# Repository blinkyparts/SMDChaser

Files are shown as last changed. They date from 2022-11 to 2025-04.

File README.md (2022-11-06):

# SMD_Lauflicht

The running light is achieved by a circuit of a clockgenerator NE555 (U1) and two shift registers TI4017 (U2, U3). The NE555 uses the clock signal to shift one bit through both shift registers. At the end the circuit is reset and the cycle starts anew. The outputs of U2 controls the 20 LEDs (D1-D20). Since the TI4017 only has 10 outputs, one output controls  two LEDs. U3 controls one transistor each (Q1, Q2) using two outputs, which alternately pull D1-D10 or D11-D20 to GND. This process repeats itself.



- Status: **Complete**
- Difficulty: **4/5**

### Parts List

| Pos.|References 	| Value 		| Quantity | 
| --- | --- | --- | --- |
|1 | C1, C2 	| 100n F 		| 2 | 
|2 |	C 	| 1µ F 		| 1 |
|3 | R1-R20 	| 82 Ohm 		| 20 |
|4 | R21, R22 	| 100k Ohm 		| 2 |
|5 | R23, R24 	| 1k Ohm 		| 2 |
|6 | D1-D20 	| LED 		| 20 |
|7 | U1 	| NE555 		| 1 |
|8 | U2, U3 	| TI4017 		| 2 |
|9 | SW1 	| SW_DPDT_x2  		| 1 |
|10 | Q1, Q2 	| BC850 		| 2 |
|12 | Battery Holder	| Battery_Holder	| 1 |
|13 | Battery 	| CR2032 		| 1 |
|14 | PCB 	| SMD-Lauflicht		| 1 |

### Manual
You can find the manual and pictures of every step in the manual folder.

## PCB Layout
The PCB-Layout can be found on Github: tbd

## Video
A video of the running PCB can be found here: [YouTube](https://youtu.be/Xx-zP-Ia8_w)

## Copyright and Authorship
- PCB-Layout: [CC-BY-SA 4.0](https://creativecommons.org/licenses/by-sa/4.0/) - [Taxxizz](https://twitter.com/Taxxizz)
- Manual (TeX): [LPPL](https://www.latex-project.org/lppl.txt) - [Marei Peischl](https://peitex.de)
- Manual (pdf): [CC-BY-SA 4.0](https://creativecommons.org/licenses/by-sa/4.0/) - [Binary Kitchen e.V.](https://www.binary-kitchen.de)

### Buy Soldering Kits
If you want to buy the parts and PCB for a soldering kit you can find everything here: [shop.blinkyparts.com - Running Light](https://shop.blinkyparts.com/en/SMD-running-light-Soldering-kit-for-the-proper-learning-of-soldering-SMD-components/blink233142)

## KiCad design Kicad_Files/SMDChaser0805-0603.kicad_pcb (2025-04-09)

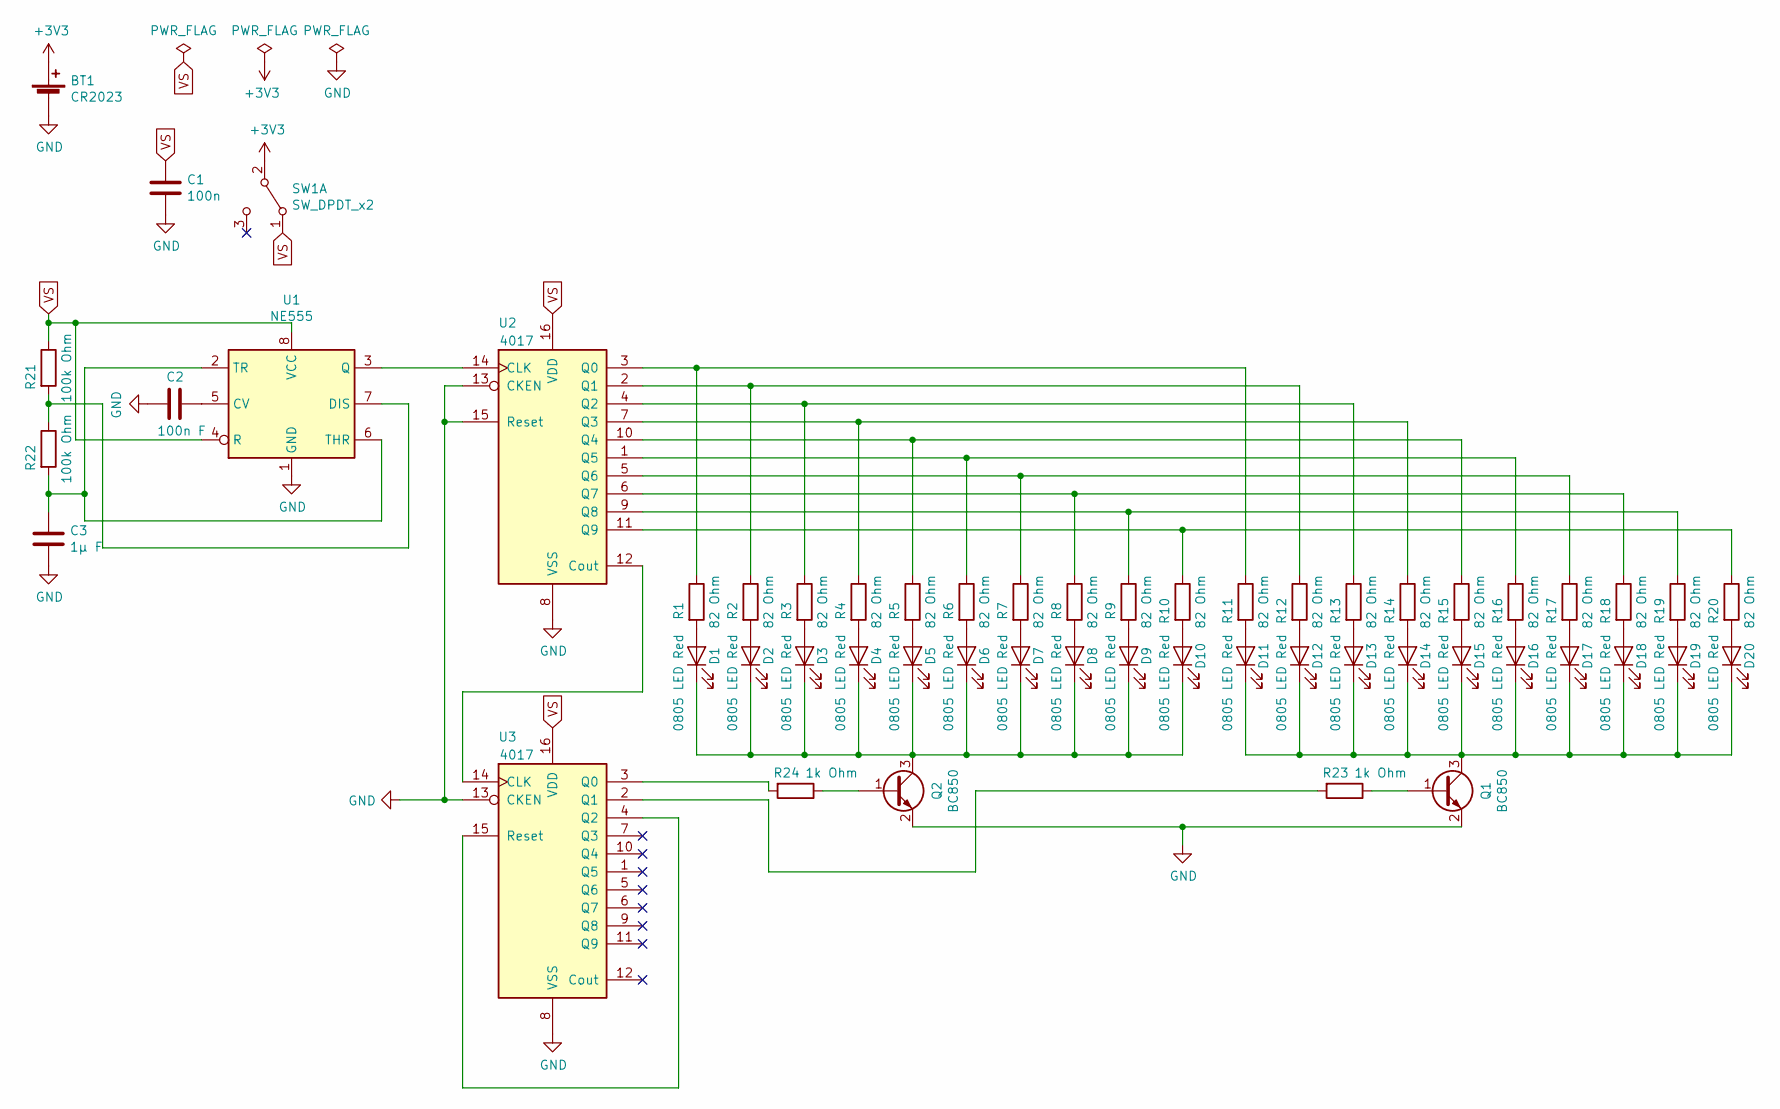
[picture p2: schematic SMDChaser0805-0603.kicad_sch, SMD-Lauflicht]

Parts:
BT1: CR2023; BatteryHolder_Keystone_1060_1x2032
C1: 100n; C_0805_2012Metric_Pad1.15x1.40mm_HandSolder
C2: 100n F; C_0805_2012Metric_Pad1.15x1.40mm_HandSolder
C3: 1µ F; C_0805_2012Metric_Pad1.15x1.40mm_HandSolder
D1, D2, D3, D4, D5, D6, D7, D8, D9, D10, D11, D12, D13, D14, D15, D16, D17, D18, D19, D20: 0805 LED Red; LED_0805_2012Metric_Pad1.15x1.40mm_HandSolder_simple_drawing
Q1, Q2: BC850; SOT-23
R1, R2, R3, R4, R5, R6, R7, R8, R9, R10, R11, R12, R13, R14, R15, R16, R17, R18, R19, R20: 82 Ohm; R_0603_1608Metric_Pad1.05x0.95mm_HandSolder
R21, R22: 100k Ohm; R_0805_2012Metric_Pad1.15x1.40mm_HandSolder
R23, R24: 1k Ohm; R_0603_1608Metric_Pad1.05x0.95mm_HandSolder
SW1: SW_DPDT_x2; smd_switch_slide
U1: NE555; SOIC-8_3.9x4.9mm_P1.27mm
U2, U3: 4017; SOP-16_4.4x10.4mm_P1.27mm_simple_drawing

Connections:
+3V3: BT1.1 (+), SW1.2 (B)
GND: BT1.2 (-), C1.1, C2.1, C3.1, Q1.2 (E), Q2.2 (E), U1.1 (GND), U2.8 (VSS), U2.13 (CKEN), U2.15 (Reset), U3.8 (VSS), U3.13 (CKEN)
unnamed: C2.2, U1.5 (CV)
unnamed: C3.2, R22.2, U1.2 (TR), U1.6 (THR)
unnamed: D1.1 (K), D2.1 (K), D3.1 (K), D4.1 (K), D5.1 (K), D6.1 (K), D7.1 (K), D8.1 (K), D9.1 (K), D10.1 (K), Q2.3 (C)
unnamed: D1.2 (A), R1.2
unnamed: D2.2 (A), R2.2
unnamed: D3.2 (A), R3.2
unnamed: D4.2 (A), R4.2
unnamed: D5.2 (A), R5.2
unnamed: D6.2 (A), R6.2
unnamed: D7.2 (A), R7.2
unnamed: D8.2 (A), R8.2
unnamed: D9.2 (A), R9.2
unnamed: D10.2 (A), R10.2
unnamed: D11.1 (K), D12.1 (K), D13.1 (K), D14.1 (K), D15.1 (K), D16.1 (K), D17.1 (K), D18.1 (K), D19.1 (K), D20.1 (K), Q1.3 (C)
unnamed: D11.2 (A), R11.2
unnamed: D12.2 (A), R12.2
unnamed: D13.2 (A), R13.2
unnamed: D14.2 (A), R14.2
unnamed: D15.2 (A), R15.2
unnamed: D16.2 (A), R16.2
unnamed: D17.2 (A), R17.2
unnamed: D18.2 (A), R18.2
unnamed: D19.2 (A), R19.2
unnamed: D20.2 (A), R20.2
unnamed: Q1.1 (B), R23.1
unnamed: Q2.1 (B), R24.1
unnamed: R1.1, R11.1, U2.3 (Q0)
unnamed: R10.1, R20.1, U2.11 (Q9)
unnamed: R2.1, R12.1, U2.2 (Q1)
unnamed: R3.1, R13.1, U2.4 (Q2)
unnamed: R4.1, R14.1, U2.7 (Q3)
unnamed: R5.1, R15.1, U2.10 (Q4)
unnamed: R6.1, R16.1, U2.1 (Q5)
unnamed: R7.1, R17.1, U2.5 (Q6)
unnamed: R8.1, R18.1, U2.6 (Q7)
unnamed: R9.1, R19.1, U2.9 (Q8)
unnamed: R21.2, R22.1, U1.7 (DIS)
unnamed: R23.2, U3.2 (Q1)
unnamed: R24.2, U3.3 (Q0)
unnamed: U1.3 (Q), U2.14 (CLK)
unnamed: U2.12 (Cout), U3.14 (CLK)
unnamed: U3.4 (Q2), U3.15 (Reset)
VS: C1.2, R21.1, SW1.1 (A), U1.4 (R), U1.8 (VCC), U2.16 (VDD), U3.16 (VDD)

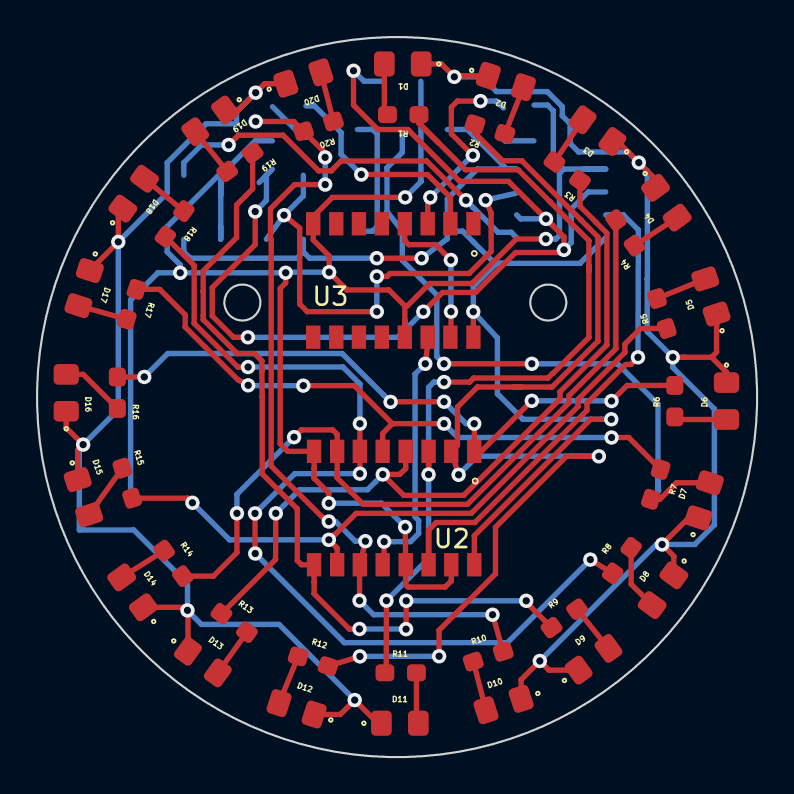
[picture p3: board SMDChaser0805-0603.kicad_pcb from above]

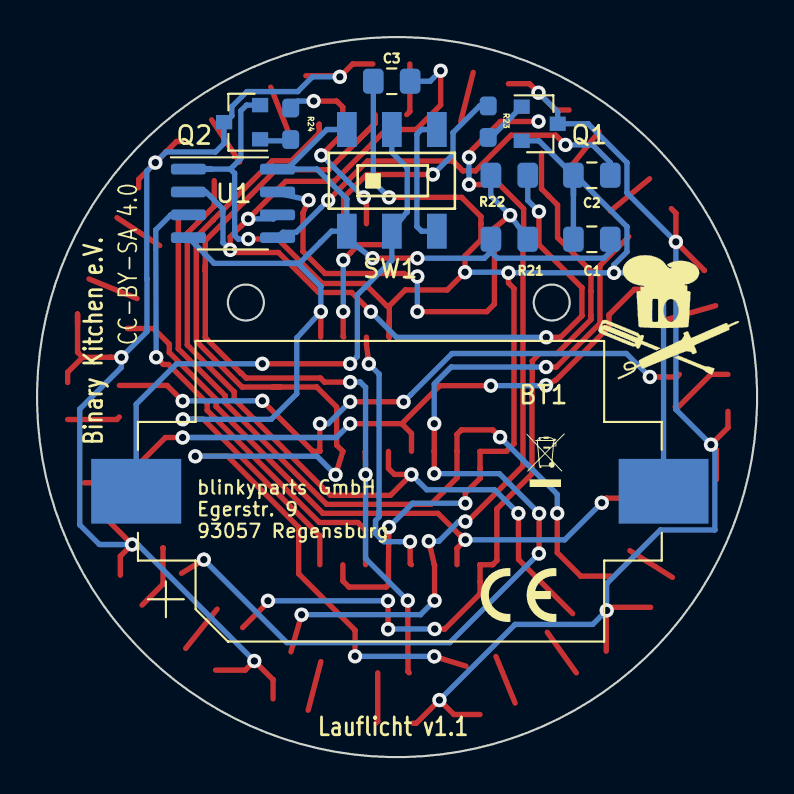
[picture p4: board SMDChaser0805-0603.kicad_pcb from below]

Board: 2 copper layers, 40.0 x 40.0 mm, 56 parts (14 on the bottom side), 45 nets.

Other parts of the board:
ce-symbol_mask_3mm: G***; ce-icon_3mm
weee-symbol_mask_3mm: G***; weee-icon_3mm

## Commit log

2022-11-29 exchanged cr2032 battery holder
    [SMD Lauflicht 0805-0603 v1_1.kicad_pcb]
2022-11-29 created gerber-files
    [SMD Lauflicht 0805-0603 v1_1-B_Adhesive.gbr, SMD Lauflicht 0805-0603 v1_1-B_Cu.gbr, SMD Lauflicht 0805-0603 v1_1-B_Mask.gbr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]
2025-04-09 moved some files and added v1.1
    [SMD Lauflicht 0805-0603 v1_1-B_Adhesive.gbr, SMD Lauflicht 0805-0603 v1_1-B_Paste.gbr, SMD Lauflicht 0805-0603 v1_1-B_Silkscreen.gbr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]
